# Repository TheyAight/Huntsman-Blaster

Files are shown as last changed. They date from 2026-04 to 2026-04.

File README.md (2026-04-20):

# Huntsman AI Tracking Blaster



Video Link: https://youtu.be/vG-90r8YBCc

# Team Name
SubPar
# Project Description
I’ve been working on a project that turns a foam dart blaster into a fully autonomous sentry turret using YOLO11. Basically, the AI acts as the "brain," constantly scanning the room to find and lock onto targets in real-time. Once it spots something, it automatically tracks the movement and lets darts fly. It’s been an awesome challenge getting the software to talk to the hardware fast enough to actually hit a moving target.

Right now, it’s focused on the core "track and fire" loop, but I’m just getting started. I’m planning to add some cooler features down the road, like predictive aiming so it can lead targets and maybe even some basic facial recognition so it doesn't accidentally blast my friends. It’s a fun mix of computer vision and DIY engineering, and it’s honestly just satisfying to see it hunt for targets on its own.

# My Experience
- This is something I have always wanted to make since I was a little kid. This club finally gave me a reason to sink time and money into it withou feeling too guilty.
- Most of my challenges came from the hardware side of things. troublesome motors that kept spinnning when the code ended, and designing 3D part for the chassis that ended up being the wrong size after hours of printing. but I managed to push through. And also, fire.
- I had fun when everything worked according to plan. So like only .137% of the time. No but seriously this was a awesome project that helped me learn more about the hardware side of tech.
- I really enjoyed building the robot. It taught me alot about things i otherwise would have never knew. It required lots of research with circuitry, AI, and physics. I actually had to apply somethings i learned in lectures to my movement handling. It definitely required me to step outside of my comfort zone but it was all very worth it. It also gave me a reason to finally buy a Raspberry Pi(the heart of the whole project) and to study how it works.
# Finale Presentation

https://canva.link/9ayxdw6bbsx5ut7

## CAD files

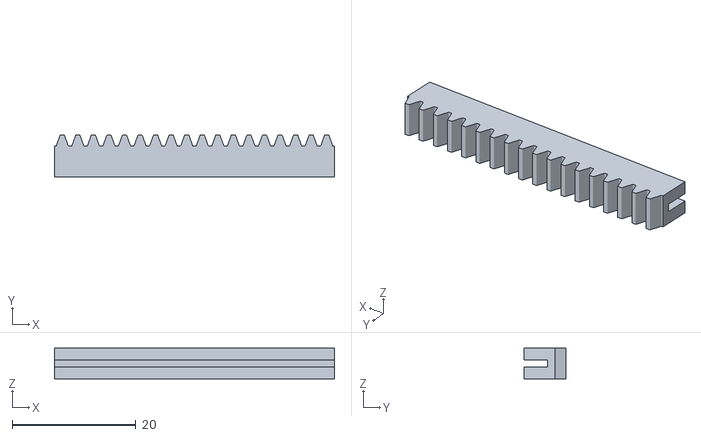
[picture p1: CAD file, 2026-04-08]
hardware/cad/Slide_Rack.stl
45.2 x 6.78 x 5.00

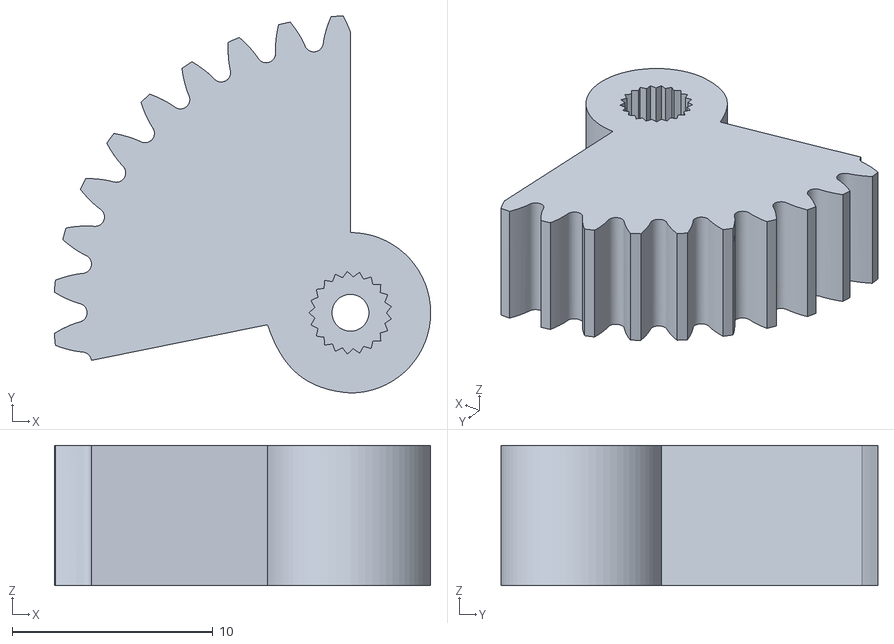
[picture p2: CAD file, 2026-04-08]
hardware/cad/Slide_Gear.stl
18.8 x 18.8 x 7.00

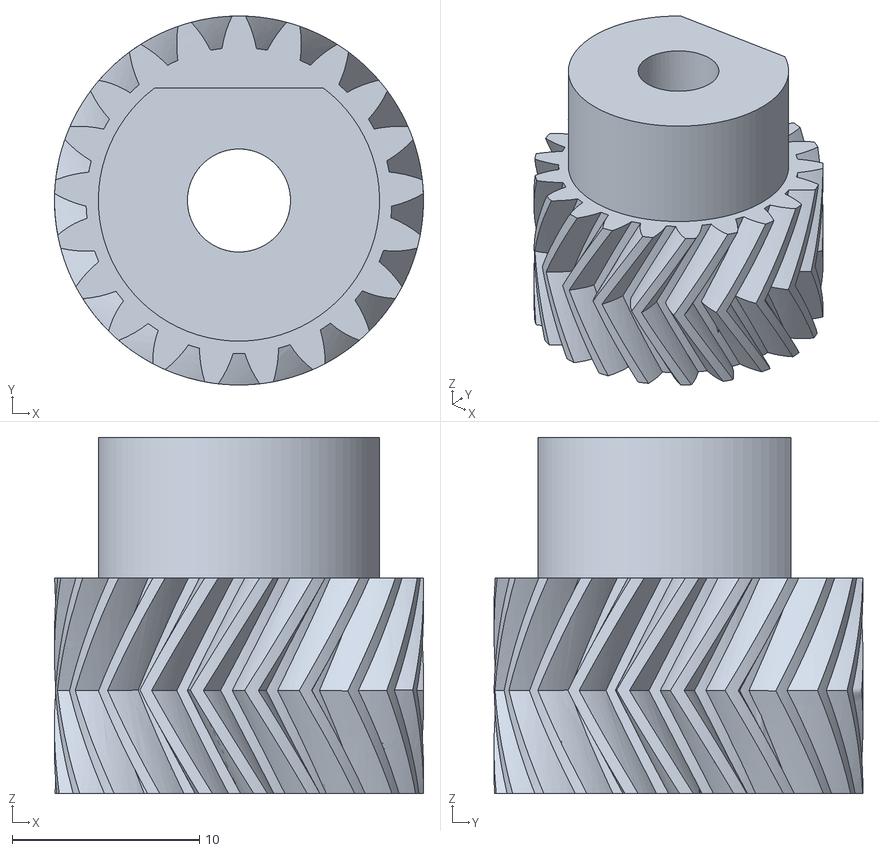
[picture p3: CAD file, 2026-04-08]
hardware/cad/21_Tooth_Herringbone_Gear_Modified.stl
19.7 x 19.7 x 19.0

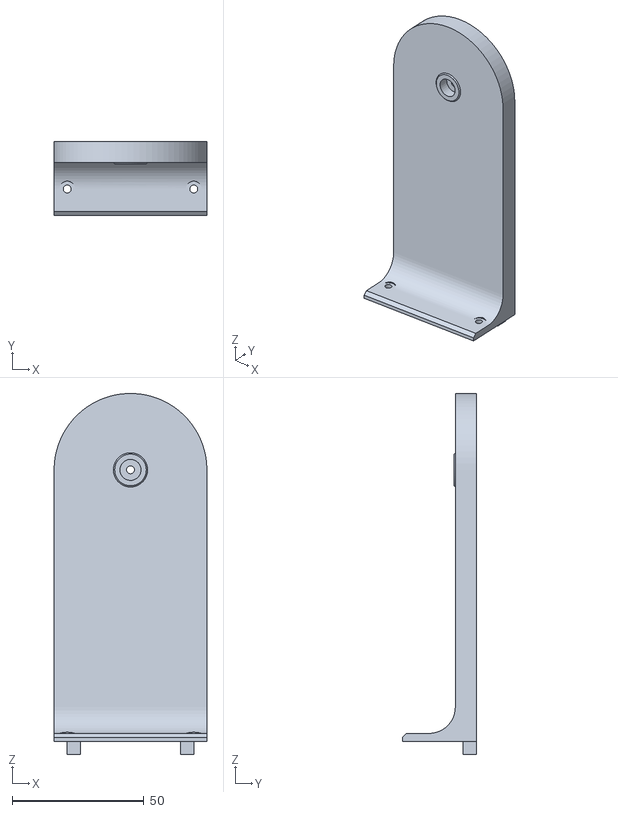
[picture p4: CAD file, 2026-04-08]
hardware/cad/Idle_Side_Support_Modified.stl
58.0 x 28.0 x 137.0

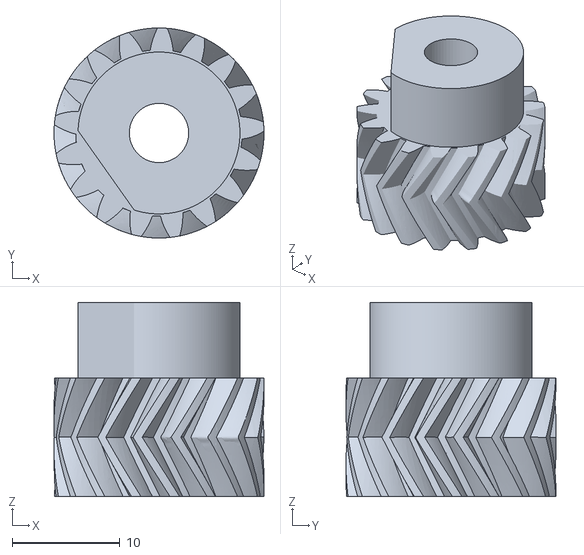
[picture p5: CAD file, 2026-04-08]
hardware/cad/17_Tooth_Herringbone_Gear_Modified.stl
19.5 x 19.5 x 18.0

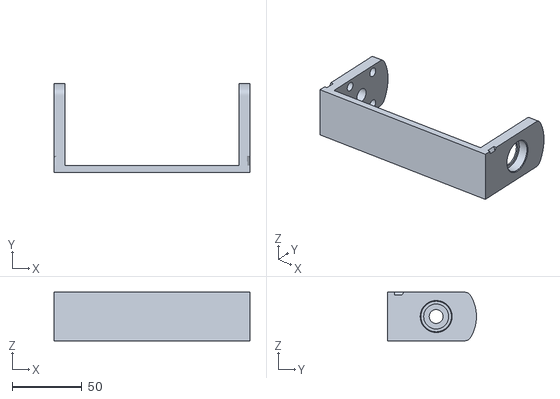
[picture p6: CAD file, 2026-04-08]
hardware/cad/Tilt_U-Mount_Modified.stl
141.0 x 64.0 x 35.0

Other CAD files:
hardware/cad/Gear_Side_Support_Modified.stl

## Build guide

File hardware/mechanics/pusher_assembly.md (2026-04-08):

The clip mania blaster from X shot has a motorized firing mechanism but the trigger must be pulled manually. This is obvoiusly not ideal for my project. So to fix that I created two 3D files. 'slide_gear.stl' and 'slide_rack.stl'.
They work by a rack and pinion system. It pushes the slide forward, sending the dart into the motors and then stock spring at the back pulls the slide back into its original position.

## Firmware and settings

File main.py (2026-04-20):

import cv2
import time
import threading
import config
from hardware import TurretHardware
from voice_control import VoiceProcessor
from ultralytics import YOLO

turret = TurretHardware()
voice = VoiceProcessor("model")
voice_thread = threading.Thread(target =voice.listen, args=(turret,), daemon=True)
voice_thread.start()


model = YOLO("yolo11n.pt")
cap = cv2.VideoCapture(0)

last_centered_time = 0
lock_start_time = 0
mosfet_start_time = 0
is_locked = False

try:
    while True:
        ret, frame = cap.read()
        if not ret: break
        now = time.time()
        results = model.track(frame, imgsz=160, persist=True, classes=0,verbose=False)
        
        if not turret.manual_mode:
            if results and results[0].boxes:
                box = results[0].boxes[0]
                x1, y1, x2, y2 = box.xyxy[0]
                height = y2 - y1
                p_x = int((x1 + x2) / 2)
                p_y = int (y1 + (height * .2))
                err_x, err_y = p_x - config.CENTER_X, p_y - config.CENTER_Y
                
                current_boundary = config.DEADZONE + config.HYSTERESIS if is_locked else config.DEADZONE
                
                turret.move_aim(err_x, err_y, current_boundary)
                
                if abs(err_x) < current_boundary and abs(err_y) < current_boundary:
                    last_centered_time = now
                    if lock_start_time == 0: locked_start_time = now
                    
                    if not is_locked and (now - lock_start_time >= config.LOCK_TIME_REQ):
                        is_locked = True
                        turret.set_mosfet(True)
                        mosfet_start_time = now
                        
                else:
                    lock_start_time = 0
                    is_locked = False
                    turret.fire(0)
                
                if is_locked and turret.mosfet_active:
                    if now - mosfet_start_time >= config.FIRE_DELAY:
                        turret.fire(-.5)
                        cv2.putText(frame, "LOCKED & FIRING!", (50,50), cv2.FONT_HERSHEY_SIMPLEX, 0.8, (0, 0, 255), 2)
                    else:
                         cv2.putText(frame, "PRIMING...", (50,50), cv2.FONT_HERSHEY_SIMPLEX, 0.8, (0, 255, 255), 2)
                         
                cv2.rectangle(frame, (int(x1), int(y1)), (int(x2) ,int(y2)), (255, 0, 0), 2)
                
            else:
                lock_start_time = 0
                is_locked = False
                turret.fire(0)
                turret.move_aim(0, 0, 0)
                
            if turret.mosfet_active and (now - last_centered_time > config.TIMEOUT_4S):
                    turret.set_mosfet(False)
                    is_locked = False
                    
        if turret.manual_mode:
            if voice.patrol_mode:
                turret.patrol()
                cv2.putText(frame, "PATROL MODE", (200, 450), 1, 2, (0, 255, 0), 2)
            else:
                cv2.putText(frame, "VOICE OVERRIDE", (200, 450), 1, 2, (0, 255, 255), 2)
                
        cv2.imshow("Secure Tracking", frame)
        if cv2.waitKey(1) & 0xFF == ord('q'): break
finally:
    print("shutting down...")
    turret.stop_all()
    cap.release()
    voice.stop()
    cv2.destroyAllWindows()
    print("All systems safe")

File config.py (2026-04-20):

MOSFET_PIN = 17
PAN_CH, TILT_CH, FIRE_CH = 0, 1, 2

FRAME_W, FRAME_H = 640, 480
CENTER_X, CENTER_Y= FRAME_W // 2, FRAME_H //2

DEADZONE= 60
HYSTERESIS = 25
TRACK_SPEED_PAN = 0.8
TRACK_SPEED_TILT = .8

LOCK_TIME_REQ = 0.2
FIRE_DELAY = 1.0
TIMEOUT_4S = 1

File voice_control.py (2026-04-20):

import json
import threading
import queue
import config
import sounddevice as sd
from vosk import Model, KaldiRecognizer

audio_queue = queue.Queue()

def callback(indata, frames, time, status):
    audio_queue.put(bytes(indata))

class VoiceProcessor:
    def __init__(self, model_path="model"):
        self.model = Model(model_path)
        self.rec = KaldiRecognizer(self.model, 16000)
        self.running = True
        self.patrol_mode = False

    def listen(self, turret):
        try:
            with sd.RawInputStream(samplerate=16000, blocksize=8000, dtype='int16',
                                   channels=1, device='hw:2,0', callback=callback):
                print("🎤 Listening for commands...")
                while self.running:
                    try:
                        data = audio_queue.get(timeout=0.5)
                        if self.rec.AcceptWaveform(data):
                            result = json.loads(self.rec.Result())
                            text = result.get("text", "").lower()
                            if text:
                    
                                print(f"DEBUG: Vosk heard -> '{text}'") 
                                self.execute(text, turret)
                        else:
                            
                            partial = json.loads(self.rec.PartialResult())
                            p_text = partial.get("partial", "").lower()
                            if p_text:
                                
                                pass
                    except queue.Empty:
                        continue
        except Exception as e:
            print(f"Mic Error: {e}")

    def execute(self, cmd, turret):
        
        if "fire" in cmd or "boom" in cmd or "blast" in cmd or "eject" in cmd:
            print("!!! VOICE ACTION: FIRING !!!")
            turret.manual_mode = True
            turret.set_mosfet(True)
            turret.fire(-.5)
            time.sleep(2)
            turret.set_mosfet(False)
            turret.fire(0)
            cmd = ""
            
        
        elif "stop" in cmd or "cease" in cmd or "wait" in cmd or "hold" in cmd:
            print("!!! VOICE ACTION: STOPPING !!!")
            turret.set_mosfet(False)
            turret.fire(0)
            turret.manual_mode = True
            self.patrol_mode = False
            turret.kit.continuous_servo[config.PAN_CH].throttle = 0
            turret.kit.continuous_servo[config.TILT_CH].throttle = 0

            
            
        elif "patrol" in cmd or "scan" in cmd or "secure" in cmd:
            self.patrol_mode = True
            turret.manual_mode = True
            
        elif "resume" in cmd or "auto" in cmd or "track" in cmd or "aggression" in cmd:
            print("!!! VOICE ACTION: AI RESUMED !!!")
            turret.manual_mode = False
            
    def stop(self):
        self.running = False
        
    def _auto_stop_fire(self, turret):
        """Helper method to ensure firing stops safely"""
        print("!!! ACTION: TURRET STOPPED !!!")
        turret.fire(0)
        turret.set_mosfet(False)
        turret.manual_mode = True
        

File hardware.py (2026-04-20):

from gpiozero import DigitalOutputDevice
from adafruit_servokit import ServoKit
import config
import time

class TurretHardware:
    def __init__(self):
        self.mosfet = DigitalOutputDevice(config.MOSFET_PIN)
        self.kit = ServoKit(channels = 16)
        self.mosfet_active = False
        self.manual_mode = False
        
    def move_aim(self, err_x, err_y, boundary):
        if self.manual_mode:
            return

        def get_scaled_speed(error):
            if abs(error) <= boundary:
                return 0
            speed = (abs(error) / 320) * config.TRACK_SPEED_TILT
            return -max(0.3, min(speed, config.TRACK_SPEED_TILT)) if error > 0 else max(0.3, min(speed, config.TRACK_SPEED_TILT))
        
        self.kit.continuous_servo[config.PAN_CH].throttle = 0

        current_tilt_speed = get_scaled_speed(err_y)
        current_pan_speed = get_scaled_speed(err_x)


        self.kit.continuous_servo[config.TILT_CH].throttle = current_tilt_speed
        self.kit.continuous_servo[config.PAN_CH].throttle = -current_pan_speed
            
    def fire(self, throttle):
        self.kit.continuous_servo[config.FIRE_CH].throttle = throttle
        
    def patrol(self):
        if int(time.time() / 5) % 2 == 0:
            self.kit.continuous_servo[config.PAN_CH].throttle = 0.4
        else:
            self.kit.continuous_servo[config.PAN_CH].throttle = -0.4
        
        self.kit.continuous_servo[config.TILT_CH].throttle = 0
        
    def set_mosfet(self, state, is_manual=False):
        
        if self.manual_mode and state and not is_manual:
            print("AI Fire Blocked: Manual Mode is Active")
            return
            
        if state:
            self.mosfet.on()
            self.mosfet_active = True
        else:
            self.mosfet.off()
            self.mosfet_active = False
            
    def stop_all(self):
        for i in range (16):
            self.kit.continuous_servo[i].throttle = 0
        self.mosfet.off()
        self.mosfet.close()
        print("\n[SAFE] Systems Stopped.")
    
        
